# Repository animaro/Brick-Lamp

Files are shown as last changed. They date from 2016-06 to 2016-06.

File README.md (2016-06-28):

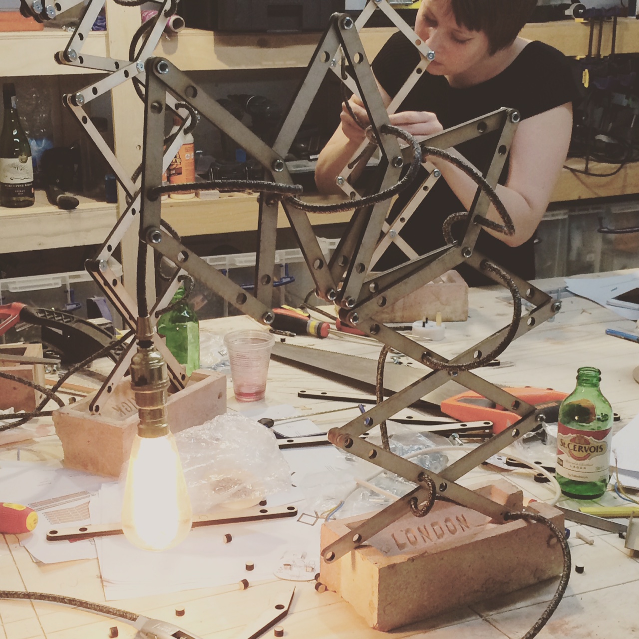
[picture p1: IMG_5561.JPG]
workshop


# Brick Lamp v.0.1

Brick lamp is an expandable table lamp design that can be made using simple laser cut pieces and a london stock brick. Please download the above pdf and laser cutting files to begin!

## License 

This design is offered to make for non-commercial use under the terms of the following license: 
[Creative Commons - Attribution-NonCommercial-ShareAlike 4.0 International](https://creativecommons.org/licenses/by-nc-sa/4.0/).

CC license icon

If you would like to use the design for anything not defined by this license please get in touch via this [contact form](http://opendesignschool.co.uk/contact/)

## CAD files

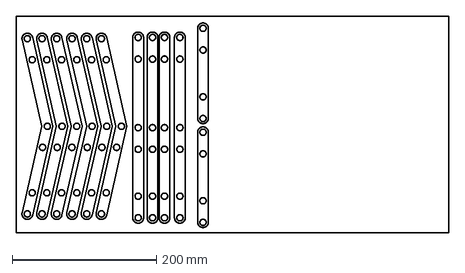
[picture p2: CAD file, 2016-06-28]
160511_cutting files 02.dxf
600.0 x 300.0 mm

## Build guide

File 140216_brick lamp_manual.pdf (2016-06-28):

# Brick lamp assembly instructions

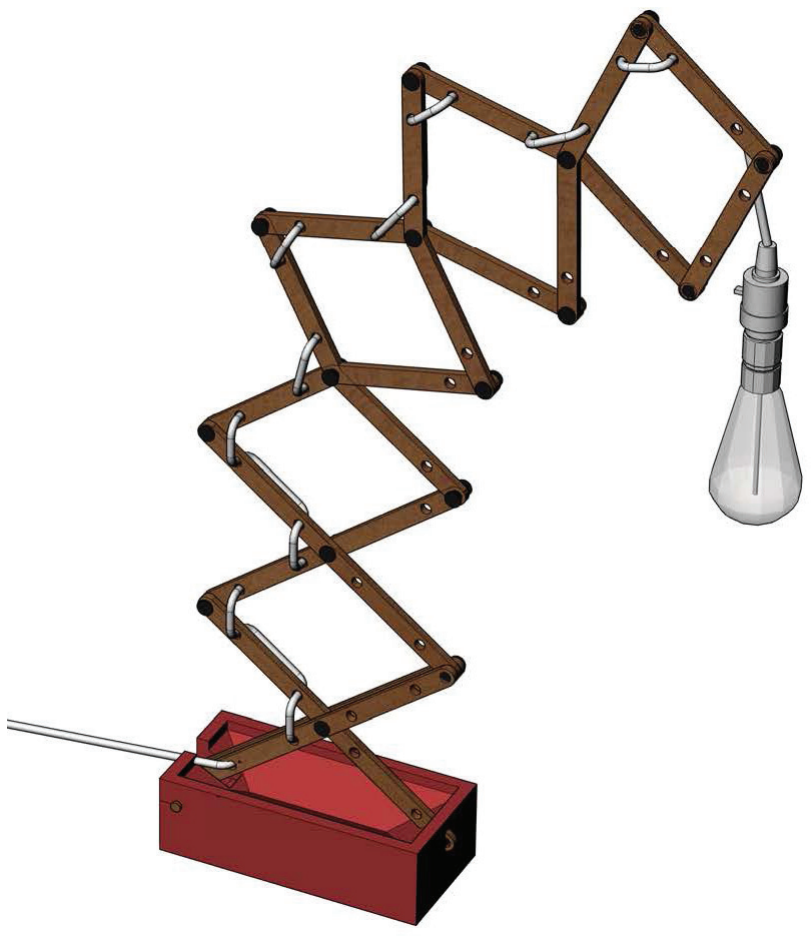
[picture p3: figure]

This work is licensed under a Creative Commons Attribution-NonCommercial 4.0 International

## Animaro

What you will need...

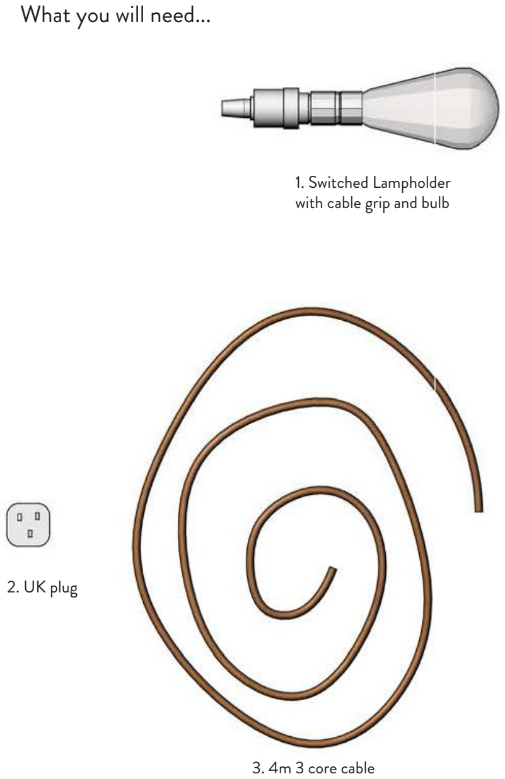
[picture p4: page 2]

1. Switched Lampholder
with cable grip and bulb
2. UK plug
3. 4m 3 core cable

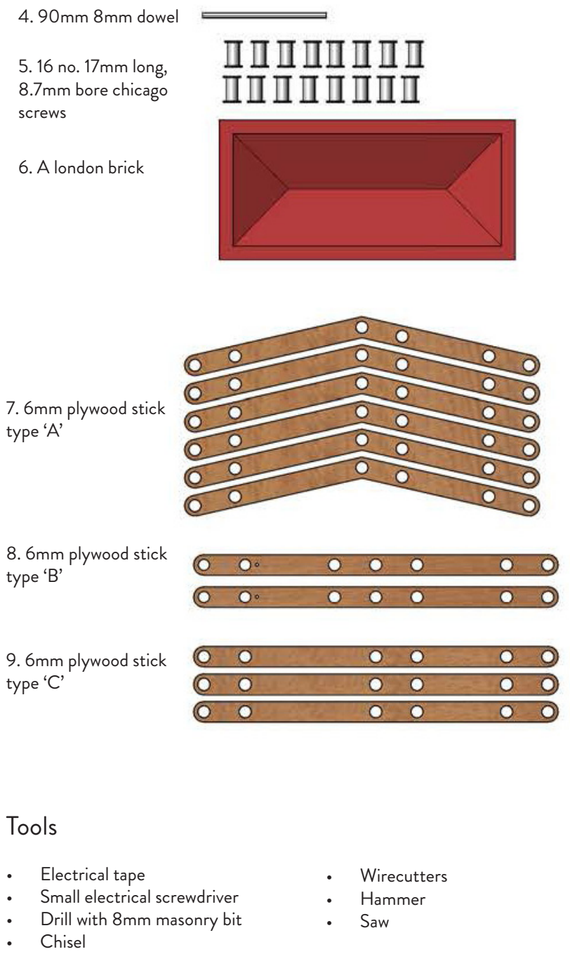
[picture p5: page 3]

## Tools

- Electrical tape
- Small electrical screwdriver
- Drill with 8mm masonry bit
- Chisel
- Wirecutters
- Hammer
- Saw
4. 90mm 8mm dowel
5. 16 no. 17mm long,
8.7mm bore chicago
screws
6. A london brick
7. 6mm plywood stick
type ‘A’
8. 6mm plywood stick
type ‘B’
9. 6mm plywood stick
type ‘C’

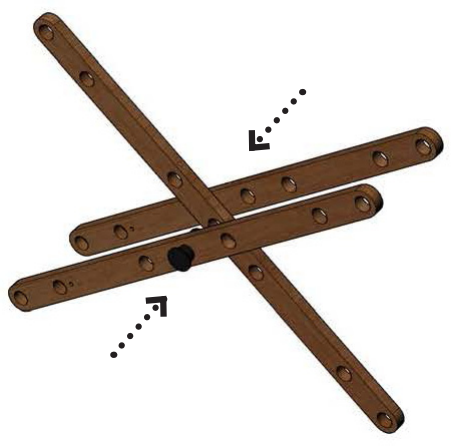
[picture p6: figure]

Attach first straight scissor together with one chicago screw. There should be a type C in the centre and 2 type Bs at the sides. Rotate the type B’s so that the small holes are at the
1. same end.

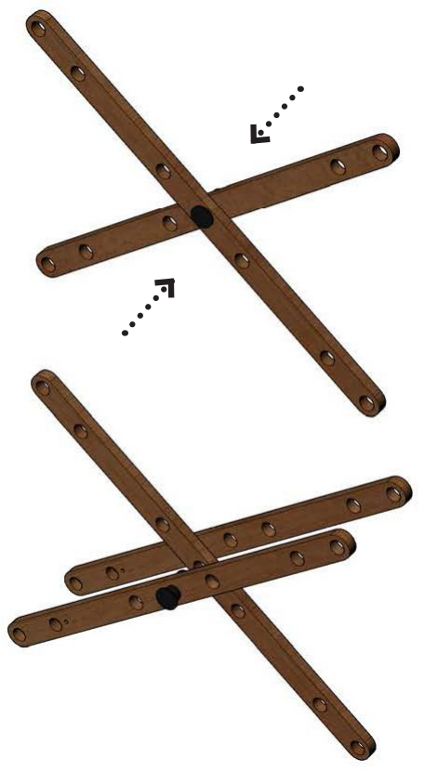
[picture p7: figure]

2. Attach next scissor together using remaining part Cs

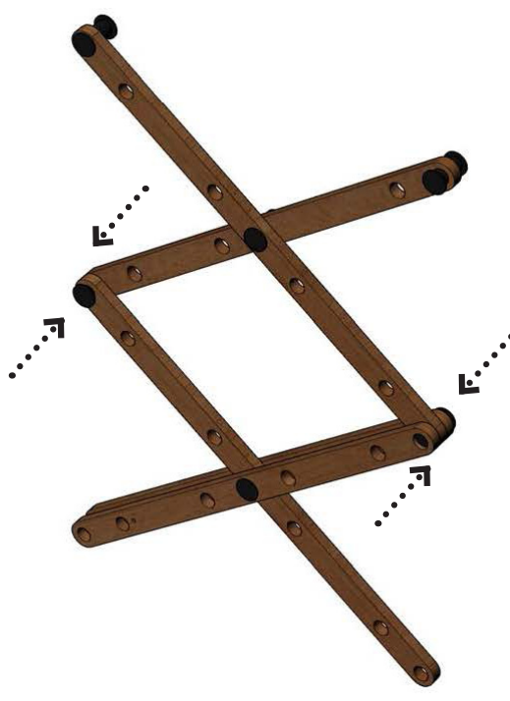
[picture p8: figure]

3. Connext 2 scissors together using chicago screws

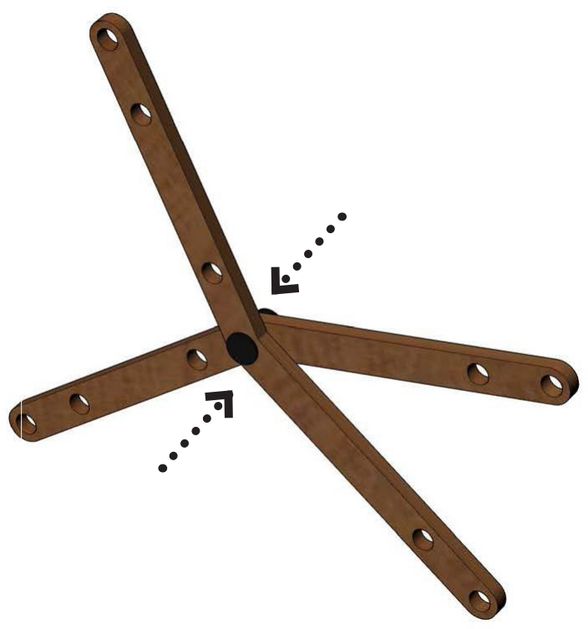
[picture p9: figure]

4. Connext type A scissor together

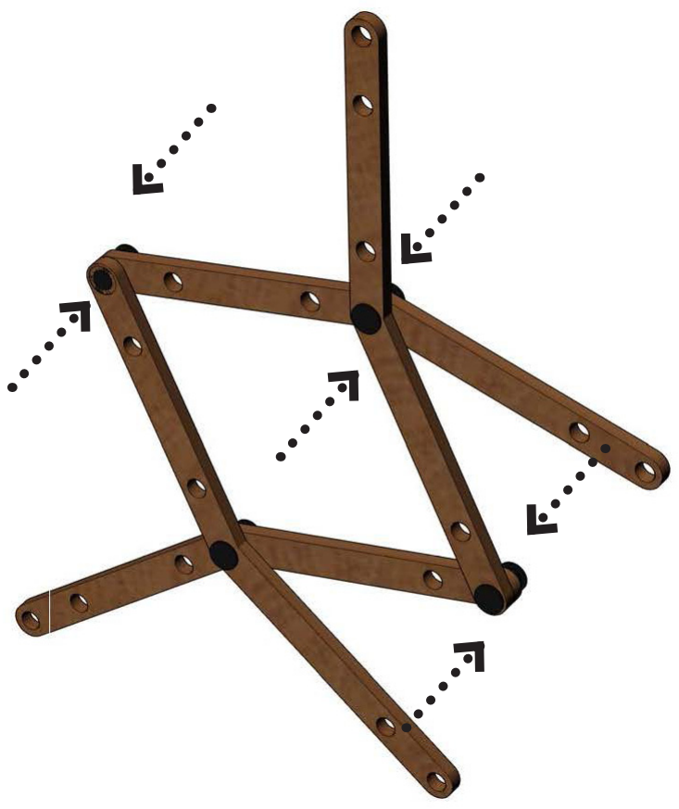
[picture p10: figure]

5. Connext second type A scissor to fist

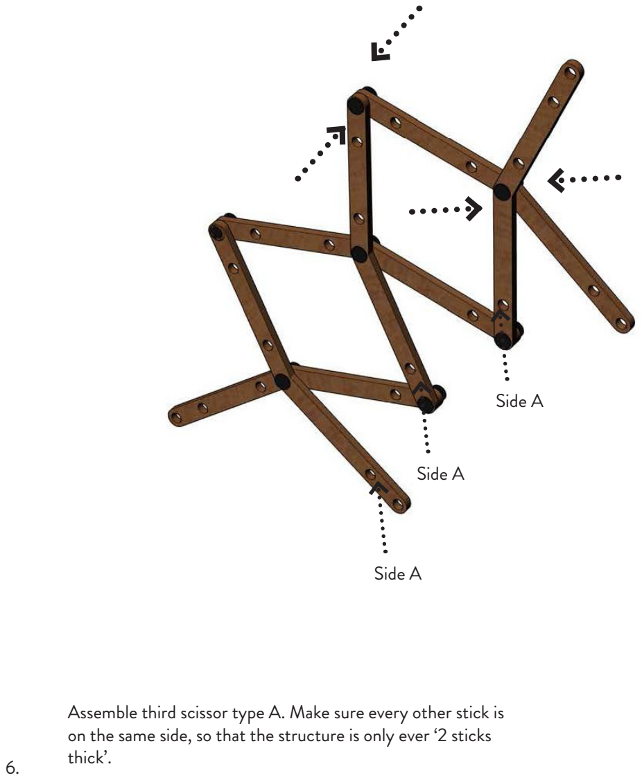
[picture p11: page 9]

Assemble third scissor type A. Make sure every other stick is on the same side, so that the structure is only ever ‘2 sticks thick’. 6.

Side A

Side A

Side A

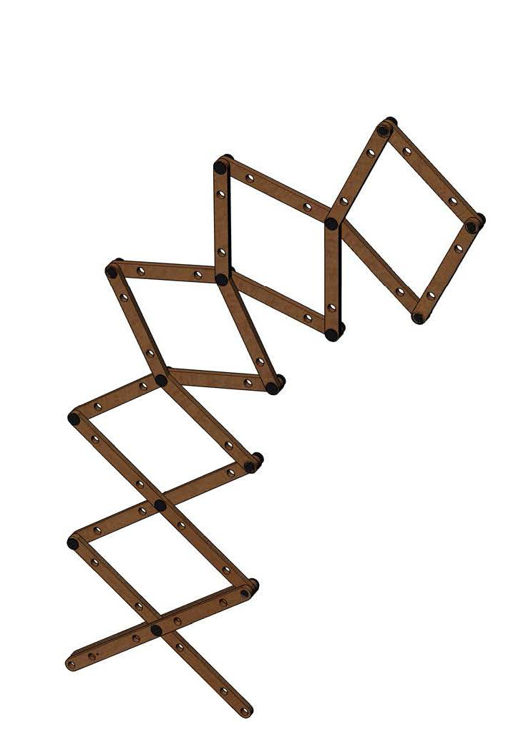
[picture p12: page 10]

7. Assemble straight section of scissor to curved section

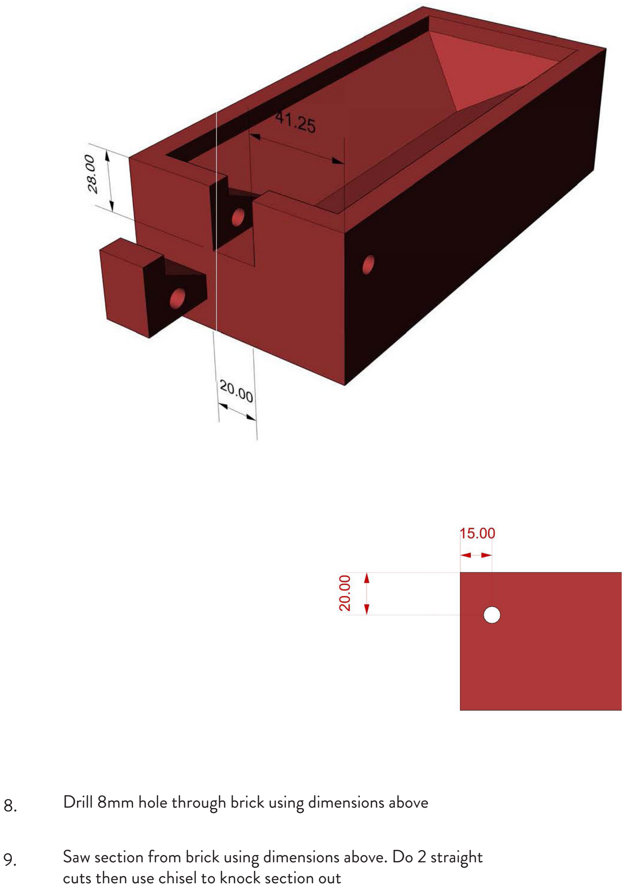
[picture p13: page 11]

8. Drill 8mm hole through brick using dimensions above

Saw section from brick using dimensions above. Do 2 straight cuts then use chisel to knock section out

9.

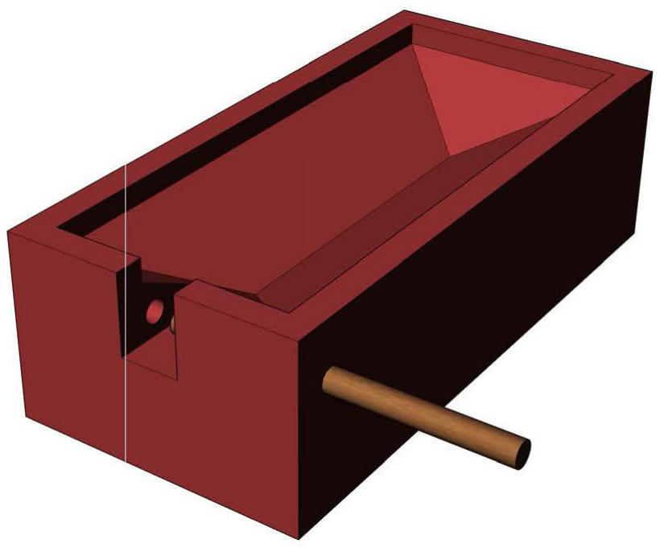
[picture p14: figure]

10. Push 8mm dowel through hole

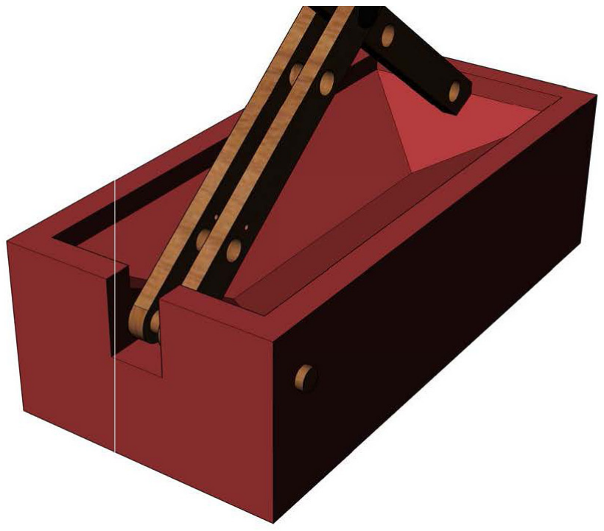
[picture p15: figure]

Push dowel through lamp mechanism and rest of brick, a hammer may be needed

11.

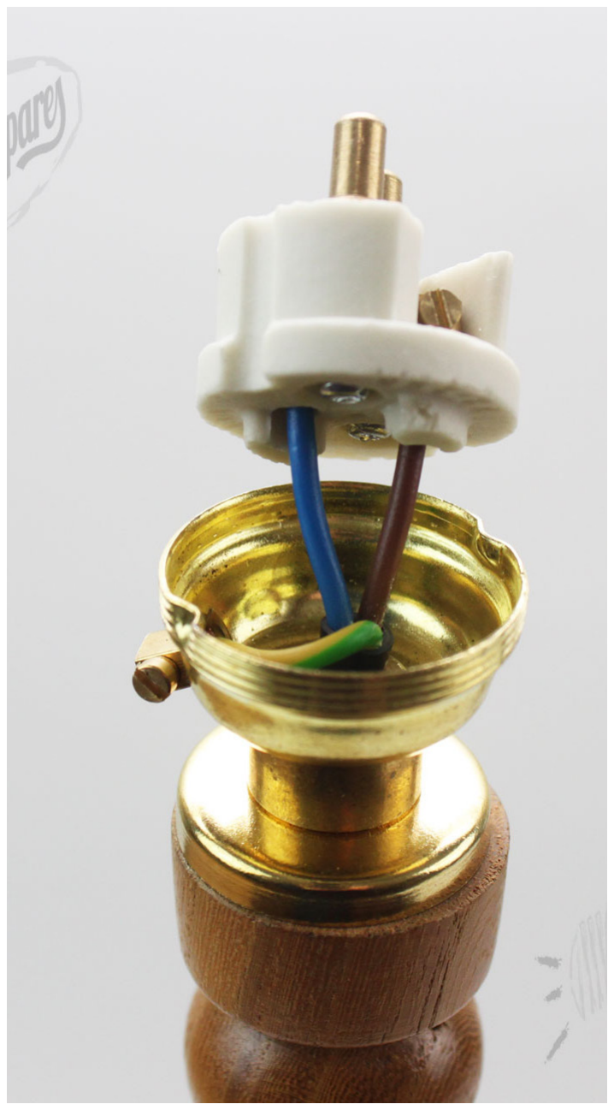
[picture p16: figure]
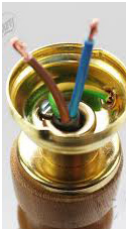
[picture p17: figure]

Wire lamp holder. Brown and blue cable need to be attached to terminals inside lampholder, which one to which doesn’t matter. Earth (yellow/green) should be connected to earth hole with small screw to tighten. Use small screwdriver to loosen terminals and wirecutter to strip back 1cm of wire, attach to terminals and tighten. Re-assemble lamp holder. 12.

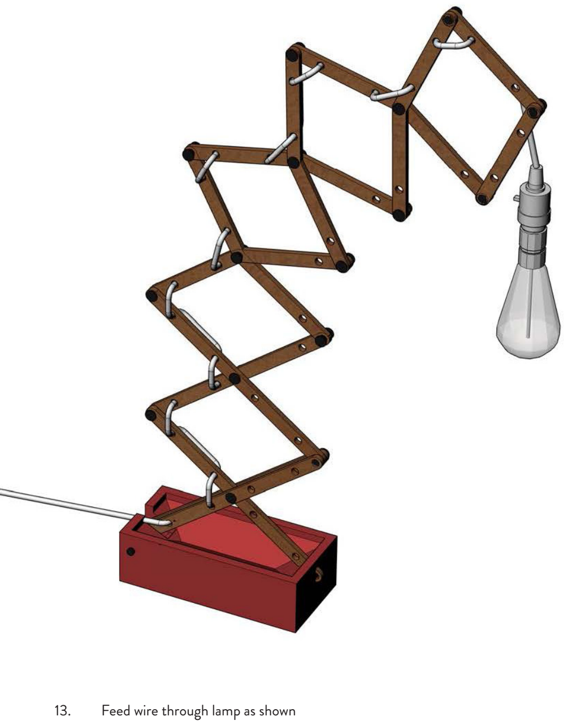
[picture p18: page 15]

13. Feed wire through lamp as shown

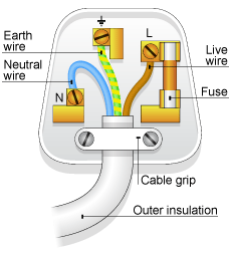
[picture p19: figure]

Wire plug using diagram above. Cut a 3sm long live (brown) wire, 4 cm neutral (blue) wire and 5cm earth (green/yellow) wire, then strip plastic bacl of 1cm of each. Fold this exposed wire in half and feed into terminal shown above. 14.

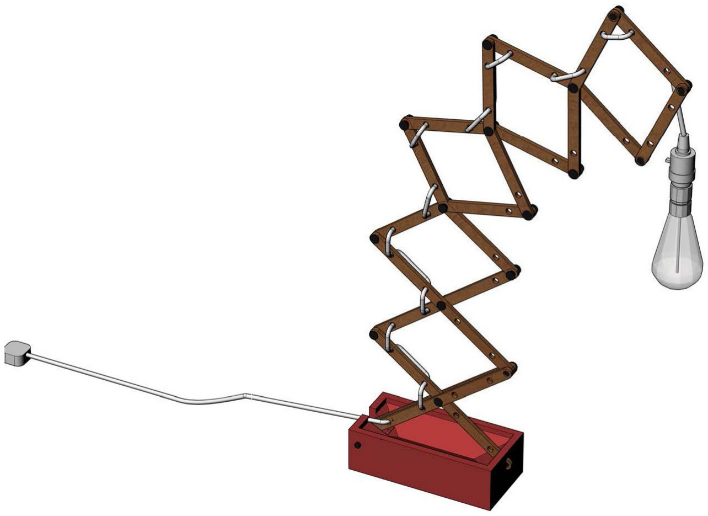
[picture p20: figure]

15. Done!
